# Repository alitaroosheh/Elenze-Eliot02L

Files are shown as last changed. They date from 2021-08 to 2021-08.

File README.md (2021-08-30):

# Elenze-Eliot02L
Elenze-Eliot02L
In this project, you could find 3 different schematics/PCB projects for a complete IoT-based Smart Plug.
The main section is ElemoW12S which means the module empowered by ESP12 wireless module and also secured by ATECC608 cryptographic coprocessor.
In this design, I've tried to expand digital IOs by means of PCF8574 and I've expanded analog inputs via 74HC4051.

The touch panel section is named Touch02 and empowered by the TS04 touch sensor.

You could find the AC/DC power converter, relays, and their drivers in the Base02 section.

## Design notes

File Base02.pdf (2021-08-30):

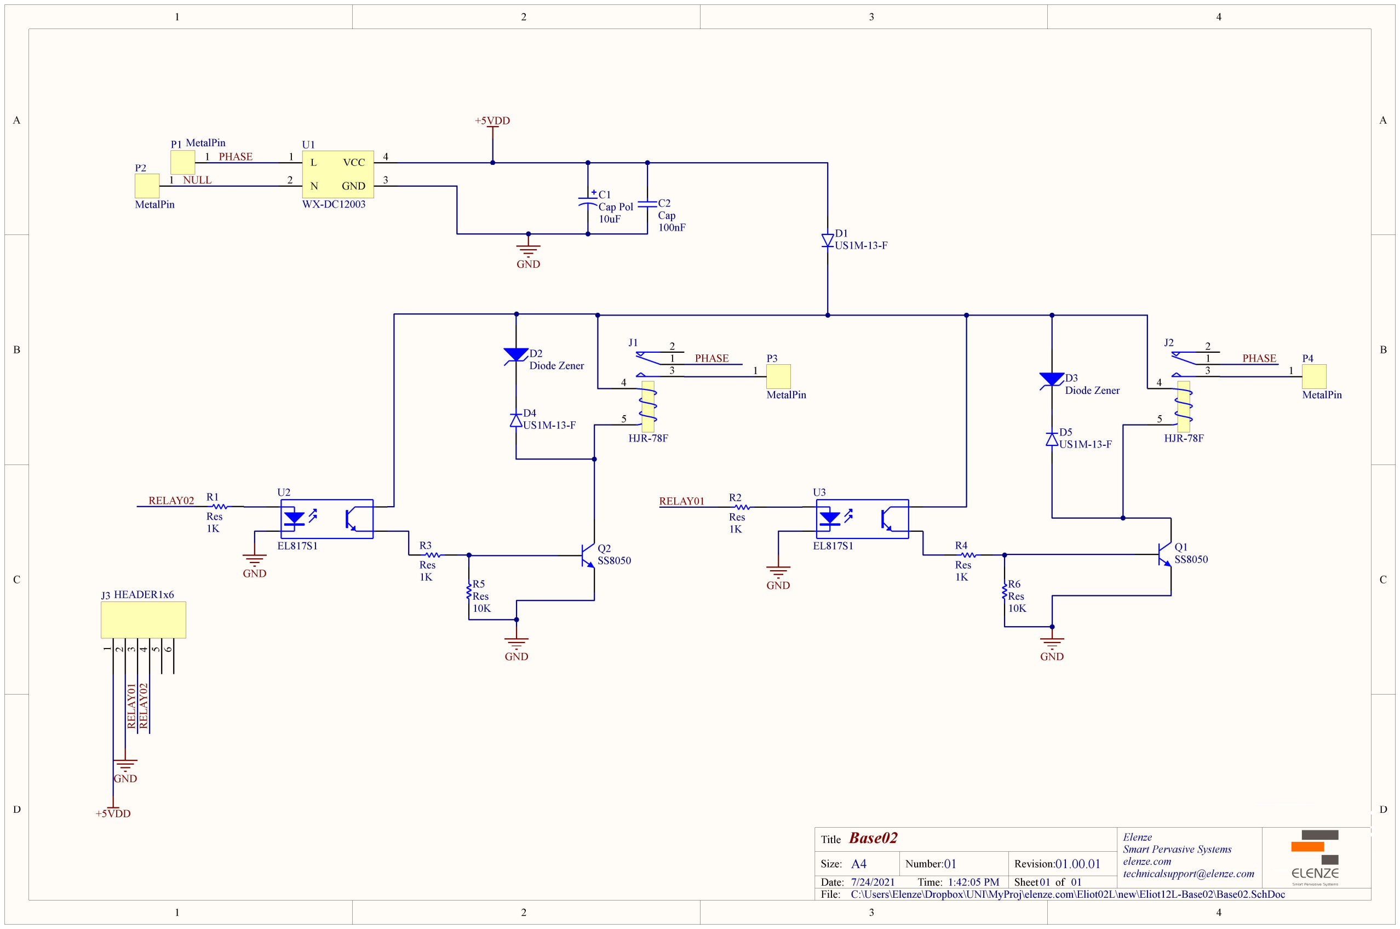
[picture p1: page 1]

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
Elenze
Smart Pervasive Systems
elenze.com
technicalsupport@elenze.com 01

## Base02

01 01.00.01
7/24/2021 | 1:42:05 PM
C:\Users\Elenze\Dropbox\UNI\MyProj\elenze.com\Eliot02L\new\Eliot12L-Base02\Base02.SchDoc

Title

Size: | Number:
Date:
File:

Revision:
Time: | Sheet | of

A4

L

1

N

2

VCC | 4
GND | 3

U1

WX-DC12003

1

P1 MetalPin

1

P2

MetalPin

GND

+5VDD

10uF

C1
Cap Pol
100nF

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
HJR-78F

U3

EL817S1

D3
Diode Zener

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
HJR-78F

U2

EL817S1

D2
Diode Zener

1K

R3
Res
GND | GND

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
RELAY02 | RELAY01

1

P3

MetalPin

1

P4

MetalPin

PHASE

NULL

PHASE | PHASE

1
2

3
4

5
6

J3 HEADER1x6 RELAY⁰¹ RELAY⁰²

GND

+5VDD

Q2
SS8050

Q1
SS8050

D4
US1M-13-F

D1
US1M-13-F

D5
US1M-13-F

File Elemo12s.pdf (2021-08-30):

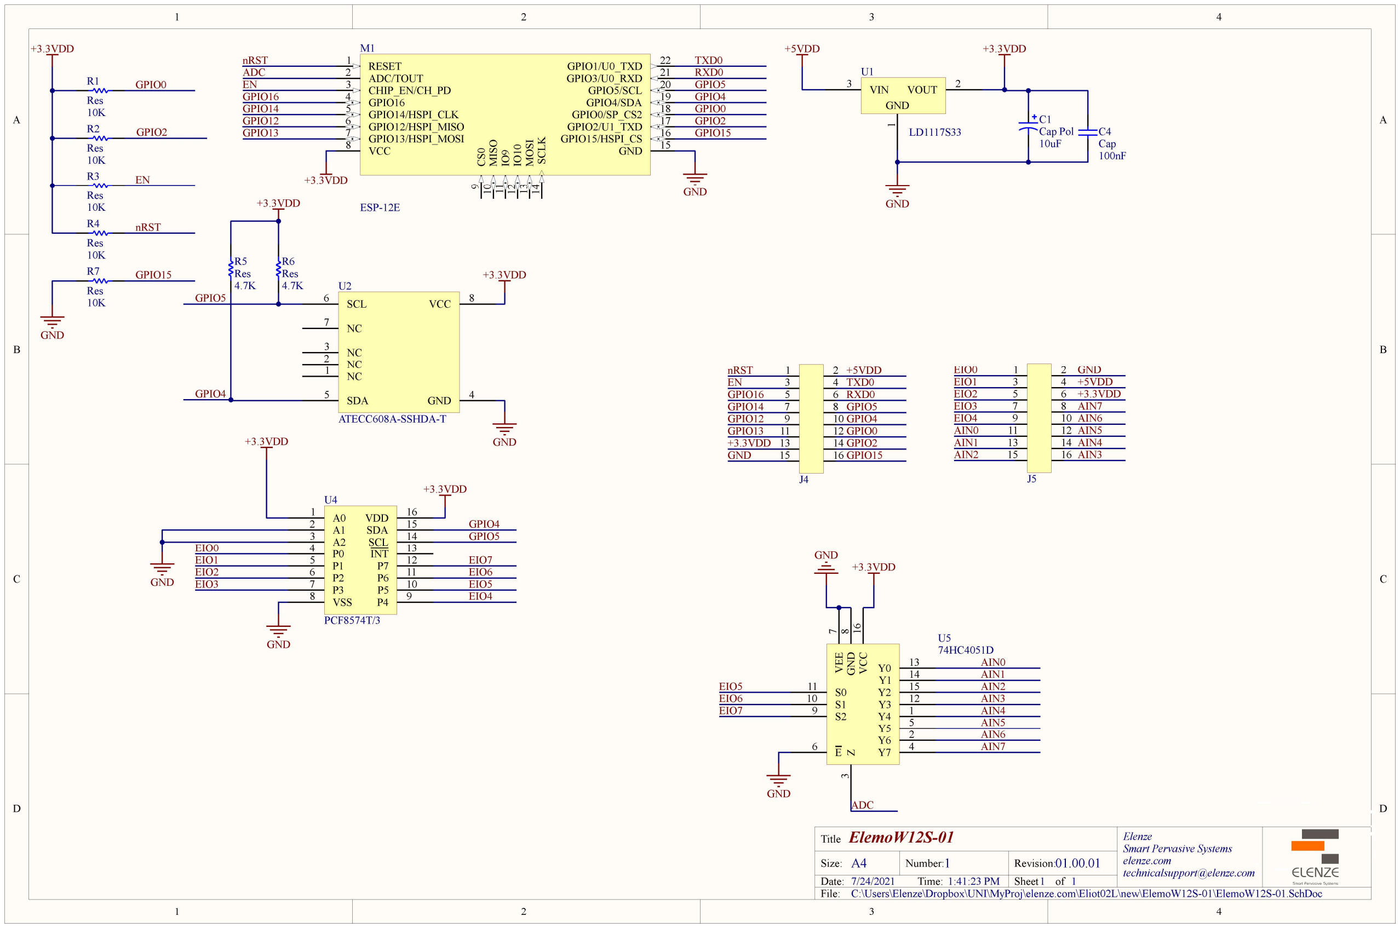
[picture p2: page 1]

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
Elenze
Smart Pervasive Systems
elenze.com
technicalsupport@elenze.com 1

## ElemoW12S-01

1 01.00.01
7/24/2021 | 1:41:23 PM
C:\Users\Elenze\Dropbox\UNI\MyProj\elenze.com\Eliot02L\new\ElemoW12S-01\ElemoW12S-01.SchDoc

Title

Size: | Number:
Date:
File:

Revision:
Time: | Sheet | of

A4

RESET 1

CHIP_EN/CH_PD 3

GPIO3/U0_RXD 21 SCLK 14 CS⁰

### 9 MOSI 13 MISO 10

GPIO0/SP_CS2 | 18
GPIO2/U1_TXD | 17
GPIO4/SDA | 19 GPIO5/SCL | 20 IO⁹ 11 IO¹⁰ 12

VCC 8

GPIO1/U0_TXD 22
ADC/TOUT 2

GPIO12/HSPI_MISO 6
GPIO13/HSPI_MOSI 7

GPIO14/HSPI_CLK 5

GPIO15/HSPI_CS 16

GPIO16 4

GND 15

M1

ESP-12E

+3.3VDD
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
+3.3VDD

GND

GPIO0

GPIO2

EN

nRST

GPIO15

nRST
ADC
EN
GPIO16
GPIO14
GPIO12
GPIO13

TXD0
RXD0
GPIO5
GPIO4
GPIO0
GPIO2
GPIO15

SCL 6

NC 7

NC 3
NC 2
NC 1
SDA 5 | GND | 4
| VCC | 8

U2

ATECC608A-SSHDA-T

VIN 3 | VOUT | 2
GND1

U1

LD1117S33

A0 1
A1 2
A2 3

P1 5
P2 6
P3 7
VSS 8
P4 | 9
P5 | 10 P6 | 11 P7 | 12 INT | 13 SCL | 14 SDA | 15 VDD | 16

P0 4

U4

PCF8574T/3

GND

+5VDD | +3.3VDD

100nF

C4
Cap

+3.3VDD

GND

+3.3VDD

4.7K

R6
Res
4.7K

R5
Res

GPIO5

GPIO4

GND

+3.3VDD

GND

+3.3VDD

GPIO4
GPIO5
EIO0
EIO1

EIO3

EIO2

EIO7
EIO6
EIO5
EIO4
Y4 | 1
Y6 | 2 Z

3

Y7 | 4
Y5 | 5

E

# 6 VEE

### 7 GND

8

S2 9

S1 10 | S0 11
Y3 | 12
Y0 | 13
Y1 | 14
Y2 | 15 VCC ¹⁶
U5
74HC4051D

+3.3VDD

GND

GND

EIO5
EIO6
EIO7

AIN0
AIN1
AIN2
AIN3
AIN4
AIN5
AIN6
AIN7

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
15 16

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
15 16

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
nRST
EN
GPIO16
GPIO14
GPIO12
GPIO13
+3.3VDD
GND | GPIO15 GPIO2

GPIO0

GPIO4

GPIO5

RXD0

TXD0

+5VDD | EIO0 EIO1 EIO2 EIO3 EIO4 AIN0 AIN1 AIN2

GND
+5VDD
+3.3VDD
AIN7
AIN6
AIN5
AIN4
AIN3

10uF

C1
Cap Pol

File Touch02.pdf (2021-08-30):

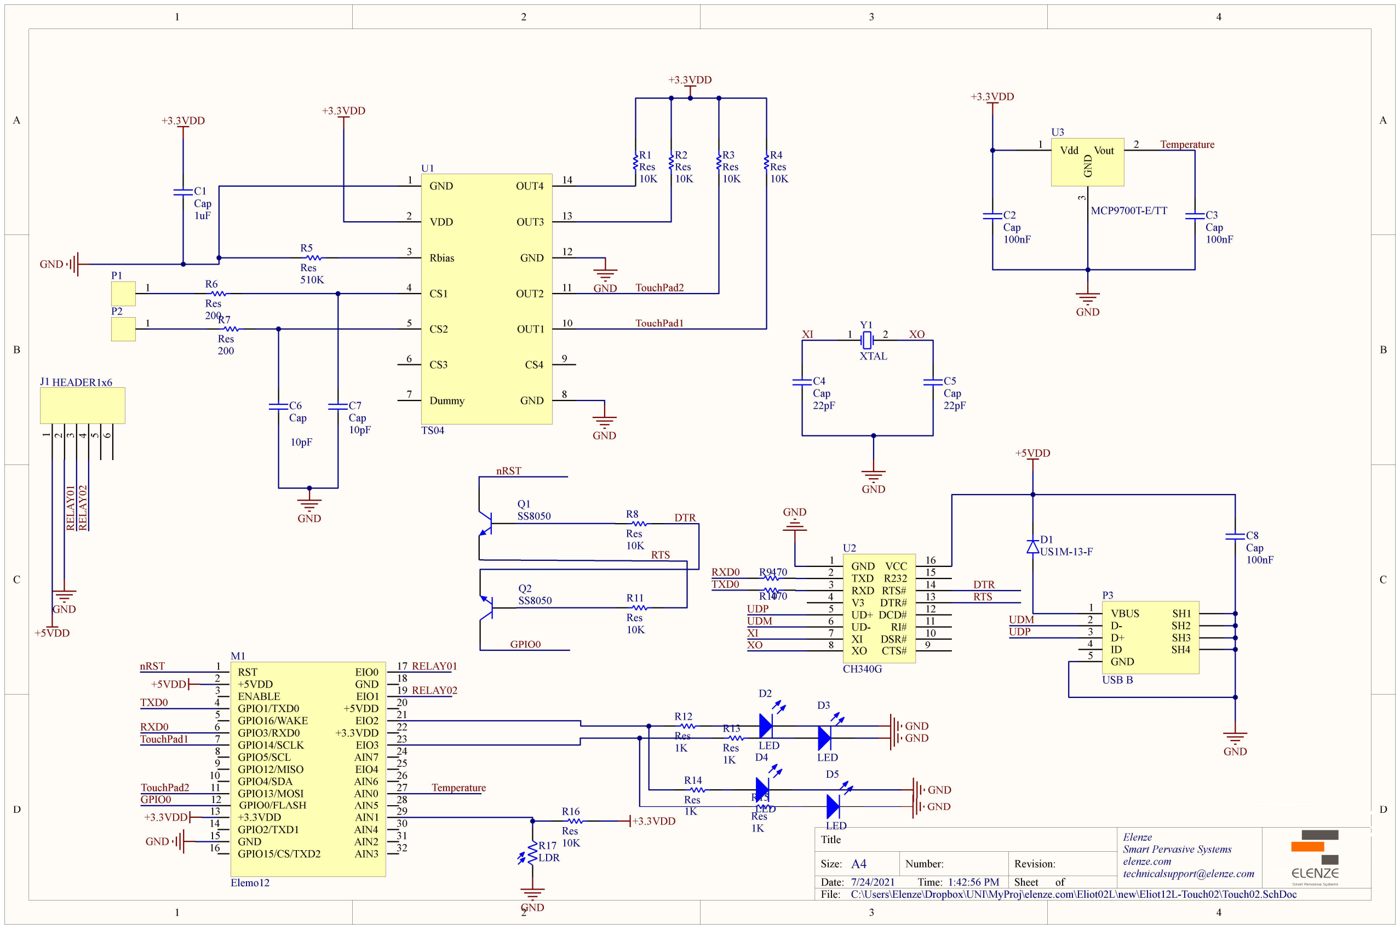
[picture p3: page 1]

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
Elenze
Smart Pervasive Systems
elenze.com
technicalsupport@elenze.com
7/24/2021 | 1:42:56 PM
C:\Users\Elenze\Dropbox\UNI\MyProj\elenze.com\Eliot02L\new\Eliot12L-Touch02\Touch02.SchDoc

Title

Size: | Number:
Date:
File:

Revision:
Time: | Sheet | of

A4

+3.3VDD

GND

GND

+3.3VDD

GND

GND

GND

+3.3VDD

RST 1

ENABLE 3

GPIO16/WAKE 5

GPIO14/SCLK 7

GPIO12/MISO 9

GPIO13/MOSI 11

+3.3VDD 13

GND 15
GPIO15/CS/TXD2 16

GPIO2/TXD1 14

GPIO0/FLASH 12

GPIO4/SDA 10

GPIO5/SCL 8

GPIO3/RXD0 6

GPIO1/TXD0 4

+5VDD 2

EIO0 | 17
EIO1 | 19
EIO2 | 21
EIO3 | 23
EIO4 | 25
AIN0 | 27
AIN1 | 29
AIN2 | 31
AIN3 | 32
AIN4 | 30
AIN5 | 28
AIN6 | 26
AIN7 | 24
+3.3VDD | 22
+5VDD | 20
GND | 18

M1

Elemo12

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
100nF

C2
Cap
100nF

C3
Cap

10pF

C7
Cap

10pF

C6
Cap

1uF

C1
Cap

+3.3VDD

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
GND 1

VDD 2

Rbias 3

CS1 4

CS2 5

CS3 6

Dummy 7 | GND | 8
| CS4 | 9
OUT1 | 10
OUT2 | 11
GND | 12
OUT3 | 13
OUT4 | 14

U1

TS04

TouchPad2

TouchPad1

1

P1

1

P2

510K

R5
Res

GND

# +5VDD RELAY⁰¹ RELAY⁰²

1
2

3
4

5
6

J1 HEADER1x6

10K

R8
Res

10K

R11
Res

GPIO0

nRST

DTR

RTS
GND 1
TXD 2
RXD 3
V3 4
UD+ 5
UD- 6
XI 7
XO 8 | CTS# | 9
DSR# | 10 RI# | 11 DCD# | 12 DTR# | 13 RTS# | 14 R232 | 15 VCC | 16

U2

CH340G

XI
XO

DTR
RTS

USB B

VBUS 1
D- 2
D+ 3
ID 4
GND 5

SH4

SH3

SH2

SH1

P3

GND

+5VDD

100nF

C8
Cap

UDP
UDM | UDM
| UDP

GND

R9470

R10470

RXD0
TXD0 Q2
SS8050

Q1
SS8050

D1
US1M-13-F

1 2

Y1

XTAL

22pF

C4
Cap
22pF

C5
Cap

GND

XI | XO

GND

+5VDD

+3.3VDD

Temperature

RELAY01

RELAY02
TXD0

RXD0

nRST

GPIO0

TouchPad1

TouchPad2

Vdd 1 | GND

3

Vout 2

U3

MCP9700T-E/TT

Temperature

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
+3.3VDD

GND

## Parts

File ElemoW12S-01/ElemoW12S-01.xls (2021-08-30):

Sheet: Part List Report
 | Component list |  |  | Bill of Materials for Project [ElemoW12S-01.PrjPcb] (No PCB Document Selected)
 | Source Data From: |  |  | ElemoW12S-01.PrjPcb
 | Project: |  |  | ElemoW12S-01.PrjPcb
 | Variant: |  |  | None
 | Report Date: |  | 7/24/2021 | 8:59 AM
 | Print Date: |  | 2021-07-24 | 8:59:53
# | LibRef | #Column Name Error:' Manufacturer 1 | #Column Name Error:' Manufacturer Part Number 1 | PartType | Description | Footprint | PackageReference | Quantity
1 | Cap Pol |  |  | Cap Pol | Polarized Capacitor (Axial) | 1206P | POLAR0.8 | 1
2 | Cap |  |  | Cap | Capacitor | 402 | RAD-0.3 | 1
3 | HEADER2x8 |  |  | 2x8 PIN HEADER | 2x8 PIN HEADER | HDR_2X8_1.27_SMT |  | 2
4 | ESP-12E |  |  | ESP-12E | ESP-12F WiFi module - developed by Ai-thinker Team | ESP8266-12E |  | 1
5 | Res |  |  | Res | Resistor | 402 | AXIAL-0.3 | 5
6 | Res |  |  | Res | Resistor | 402 | AXIAL-0.3 | 2
7 | LD1117S33CTR |  |  | LD1117S33 | IC REG LINEAR 3.3V 800MA | SOT223_4 |  | 1
8 | ATECC608A-SSHDA-T |  |  | ATECC608A-SSHDA-T | IC AUTHENTICATION CHIP 8SOIC | SO_8N |  | 1
9 | PCF8574T/3 |  |  | PCF8574T/3 | I2C IO Expander | SO_16W |  | 1
10 | 74HC4051D |  |  | 74HC4051D | CMOS ANALOG/DIGITAL MUX/DEMUX | SO_16N |  | 1
Approved |  |  |  | Notes |  |  |  | 16

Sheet: Project Information
Project Full Path | C:\Users\Elenze\Dropbox\UNI\MyProj\elenze.com\Eliot02L\new\ElemoW12S-01\ElemoW12S-01.PrjPcb
Project Filename | ElemoW12S-01.PrjPcb
Variant Name | None
Data-Source Filename | ElemoW12S-01.PrjPcb
Data-Source Full Path | C:\Users\Elenze\Dropbox\UNI\MyProj\elenze.com\Eliot02L\new\ElemoW12S-01\ElemoW12S-01.PrjPcb
Title | Bill of Materials for Project [ElemoW12S-01.PrjPcb] (No PCB Document Selected)
Total Quantity | 16
Report Time | 8:59 AM
Report Date | 7/24/2021
Report Date & Tine | 7/24/2021 8:59 AM
Output Name | Bill of Materials
Output Type | BOM_PartType
Output Generator Name | BOM
Output Generator Description | Bill of Materials
Total Actual Price | <Parameter TotalActualPrice not found>
Total Target Price | <Parameter TotalTargetPrice not found>

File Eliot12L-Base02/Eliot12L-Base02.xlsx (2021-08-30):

Comment | Designator | Footprint | LibRef | Quantity | Value
Cap Pol | C1 | EL_C_4_5 | Cap Pol | 1 | 10uF
Cap | C2 | 0402 | Cap | 1 | 100nF
US1M-13-F | D1, D4, D5 | DIO_ES1J | US1M-13-F | 3
Diode Zener | D2, D3 | DO1206 | Diode Zener | 2
HJR-78F | J1, J2 | RELAY | HJR-78F | 2
HEADER1x6 | J3 | M-Header 6 | HEADER1x6 | 1
MetalPin | P1, P2, P3, P4 | MetalPin | MetalPin | 4
SS8050 | Q1, Q2 | SOT-23 | SS8050 | 2
Res | R1, R2, R3, R4 | 0402 | Res | 4 | 1K
Res | R5, R6 | 0402 | Res | 2 | 10K
WX-DC12003 | U1 | WX-DC12003 | WX-DC12003 | 1
EL817S1 | U2, U3 | SOIC254P1030X390-4N_EL817(S1)(A)(TU)-VG | EL817S1 | 2
